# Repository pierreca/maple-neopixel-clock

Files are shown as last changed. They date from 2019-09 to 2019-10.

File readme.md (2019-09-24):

# Maple Neopixel Clock

The goal with this clock project was to learn how to use vcarve and a Shapeoko 3 milling machine.

The electronics are from spare parts I had (I'm sure better components could be found) and the code is quickly put together to make it work but is by no means considered nice or finished.

Finally the PCB was designed to be able to plug a chronodot with an arduino nano and 3 neopixel rings and 2 buttons. I could (probably should?) have chained the rings instead of connecting them separately but didn't think about it when I designed it.

This project is unlikely to evolve or change much :)

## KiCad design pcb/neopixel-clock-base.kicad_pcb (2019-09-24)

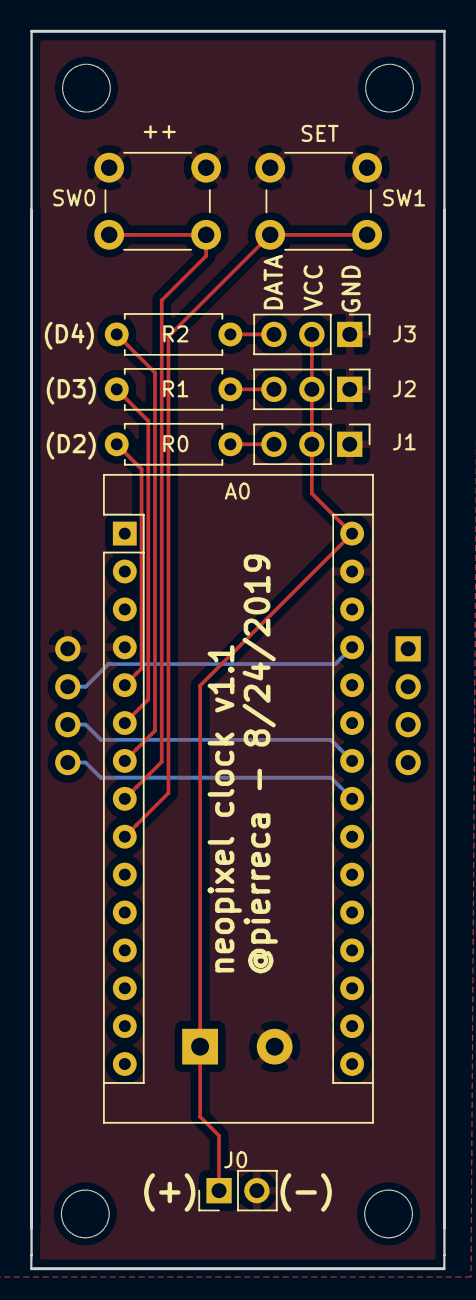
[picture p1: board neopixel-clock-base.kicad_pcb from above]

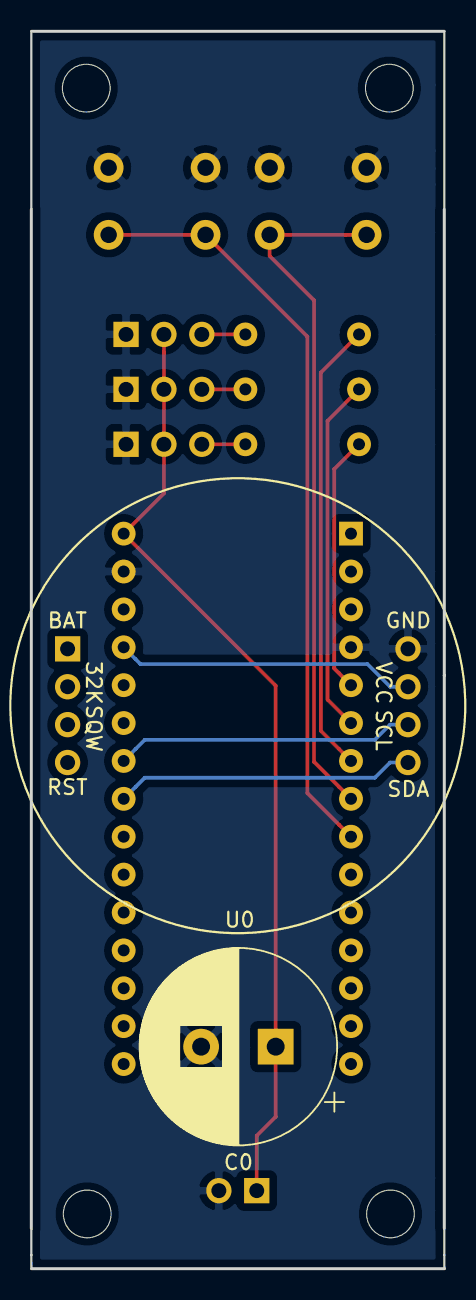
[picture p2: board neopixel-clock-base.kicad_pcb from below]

Board: 2 copper layers, 27.7 x 83.0 mm, 12 parts (2 on the bottom side), 13 nets.

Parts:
A0: Arduino_Nano_v3.x; Arduino_Nano
C0: 100uF 35V; CP_Radial_D13.0mm_P5.00mm
J0: Power; PinHeader_1x02_P2.54mm_Vertical
J1: Neopixel_12; PinHeader_1x03_P2.54mm_Vertical
J2: Neopixel_24; PinHeader_1x03_P2.54mm_Vertical
J3: Neopixel_60; PinHeader_1x03_P2.54mm_Vertical
R0, R1, R2: 300; R_Axial_DIN0207_L6.3mm_D2.5mm_P7.62mm_Horizontal
SW0, SW1: SW_Push; SW_PUSH_6mm
U0: Chronodot; chronodot

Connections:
GND: A0.4, A0.29, C0.2, J0.2, J1.1, J2.1, J3.1, SW0.1, SW1.1, U0.2
unnamed: A0.5, R0.2
unnamed: A0.6, R1.2
unnamed: A0.7, R2.2
unnamed: A0.8, SW0.2
unnamed: A0.9, SW1.2
unnamed: A0.23, U0.8
unnamed: A0.24, U0.6
unnamed: A0.27, U0.4
unnamed: A0.30, C0.1, J0.1, J1.2, J2.2, J3.2
unnamed: J1.3, R0.1
unnamed: J2.3, R1.1
unnamed: J3.3, R2.1

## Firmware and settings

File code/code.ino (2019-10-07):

// Date and time functions using a DS3231 RTC connected via I2C and Wire lib
#include <Wire.h>
#include <Adafruit_NeoPixel.h>
#include "RTClib.h"
#include <avr/interrupt.h>

#define MODE_DISPLAY 0
#define MODE_SET_HOURS 1
#define MODE_SET_MINUTES 2
#define MODE_SET_SECONDS 3

#define HOURS_PIN    2
#define HOURS_PIXELS 12

#define MINUTES_PIN  3
#define MINUTES_PIXELS 24

#define SECONDS_PIN 4
#define SECONDS_PIXELS 60

#define MAX_INTENSITY 255
#define CURRENT_SEC_ANIMATION_RAMP_TIME 600

#define INC_BTN_PIN 5
#define SET_BTN_PIN 6

RTC_DS3231 rtc;
Adafruit_NeoPixel hours_ring = Adafruit_NeoPixel(HOURS_PIXELS, HOURS_PIN, NEO_GRB + NEO_KHZ800);
Adafruit_NeoPixel minutes_ring = Adafruit_NeoPixel(MINUTES_PIXELS, MINUTES_PIN, NEO_GRB + NEO_KHZ800);
Adafruit_NeoPixel seconds_ring = Adafruit_NeoPixel(SECONDS_PIXELS, SECONDS_PIN, NEO_GRB + NEO_KHZ800);

uint8_t sec, prev_sec, current_mode;

DateTime now;

uint32_t get_pixel_color(uint8_t intensity) {
  return hours_ring.Color(intensity / 6, intensity / 2, intensity);
}

void setup () {
  Serial.begin(9600);
  
  delay(3000); // wait for console opening

  if (! rtc.begin()) {
    Serial.println("Couldn't find RTC");
    while (1);
  }

  if (rtc.lostPower()) {
    Serial.println("RTC lost power, lets set the time!");
    // following line sets the RTC to the date & time this sketch was compiled
    rtc.adjust(DateTime(F(__DATE__), F(__TIME__)));
    // This line sets the RTC with an explicit date & time, for example to set
    // January 21, 2014 at 3am you would call:
    // rtc.adjust(DateTime(2014, 1, 21, 3, 0, 0));
  }

  // set button pins as inputs
  pinMode(SET_BTN_PIN, INPUT_PULLUP);
  pinMode(INC_BTN_PIN, INPUT_PULLUP);
 
  hours_ring.begin();
  minutes_ring.begin();
  seconds_ring.begin();
  sec = 0;
  prev_sec = 0;
}

void color_pixels(Adafruit_NeoPixel& ring, uint8_t pixel) {
    ring.clear();
    for (uint8_t i = 0; i <= pixel; i++) {
        ring.setPixelColor(i, get_pixel_color(MAX_INTENSITY));
    }
    ring.show();
}

void display_hours(uint8_t hour_now) {
    uint8_t pix = hour_now % 12;
    color_pixels(hours_ring, pix);
}

void display_minutes(uint8_t minute_now) {
    uint8_t pix = (minute_now * MINUTES_PIXELS / 60) % 60;
    color_pixels(minutes_ring, pix);
}

void display_seconds(uint8_t second_now) {
    uint8_t pix = second_now % 60;
    color_pixels(seconds_ring, pix);
}

void new_minute_animation() {
  for (uint8_t i = 0; i < 60; i++) {
    seconds_ring.setPixelColor(i, 0);
    seconds_ring.show();
    delay(10);
  }
}

void light_up_current_second(uint8_t current_sec) {
  unsigned long current_sec_animation_start = millis(); 
  while (millis() < current_sec_animation_start + CURRENT_SEC_ANIMATION_RAMP_TIME) {
    unsigned long elapsed = millis() - current_sec_animation_start;
    unsigned long intensity = elapsed * MAX_INTENSITY / CURRENT_SEC_ANIMATION_RAMP_TIME;
    seconds_ring.setPixelColor(sec, get_pixel_color(intensity));
    seconds_ring.show();
  }
}

void serial_print_time(uint8_t hours, uint8_t minutes, uint8_t seconds) {
  Serial.print(hours, DEC);
  Serial.print(':');
  Serial.print(minutes, DEC);
  Serial.print(':');
  Serial.print(seconds, DEC);
  Serial.println();
}

void display_time() {
  DateTime now = rtc.now();

  display_hours(now.hour());
  display_minutes(now.minute());
  sec = now.second();

  if (sec != prev_sec) {
    serial_print_time(now.hour(), now.minute(), now.second());
    if (sec == 0) {
      // turn off all seconds pixel in a quick animation around the ring
      new_minute_animation();
    } else {   
      // light up all second pixels until now
      display_seconds(sec - 1);
    }

    // animate current seconds pixel
    light_up_current_second(sec);
    prev_sec = sec;
  }
}

void display_H() {
  hours_ring.clear();
  hours_ring.setPixelColor(3, get_pixel_color(MAX_INTENSITY));
  hours_ring.setPixelColor(9, get_pixel_color(MAX_INTENSITY));
  hours_ring.show();

  minutes_ring.clear();
  for (int i = 3; i <= 9; i++) {
    minutes_ring.setPixelColor(i, get_pixel_color(MAX_INTENSITY));
    minutes_ring.setPixelColor(i + 12, get_pixel_color(MAX_INTENSITY));
  }
  minutes_ring.show();
}

void display_M() {
  hours_ring.clear();
  hours_ring.setPixelColor(1, get_pixel_color(MAX_INTENSITY));
  hours_ring.setPixelColor(11, get_pixel_color(MAX_INTENSITY));
  hours_ring.show();

  minutes_ring.clear();
  for (int i = 3; i <= 9; i++) {
    minutes_ring.setPixelColor(i, get_pixel_color(MAX_INTENSITY));
    minutes_ring.setPixelColor(i + 12, get_pixel_color(MAX_INTENSITY));
  }
  minutes_ring.show();
}

void display_S() {
  hours_ring.clear();
  hours_ring.setPixelColor(3, get_pixel_color(MAX_INTENSITY));
  hours_ring.setPixelColor(9, get_pixel_color(MAX_INTENSITY));
  hours_ring.show();

  minutes_ring.clear();
  for (int i = 0; i <= 3; i++) {
    minutes_ring.setPixelColor(i, get_pixel_color(MAX_INTENSITY));
    minutes_ring.setPixelColor(i + 12, get_pixel_color(MAX_INTENSITY));
  }
  for (int j = 6; j <= 11; j++) {
    minutes_ring.setPixelColor(j, get_pixel_color(MAX_INTENSITY));
    minutes_ring.setPixelColor(j + 12, get_pixel_color(MAX_INTENSITY));
  }
  minutes_ring.show();
}

uint8_t value_set;

bool increase_value_set_if_btn_pressed(uint8_t modulo) {
  bool changed = digitalRead(INC_BTN_PIN) == LOW;
  if (changed) {
    delay(200);
    value_set++;
    if (value_set > modulo - 1) {
      value_set = 0;
    }
  }
  for (int i = 0; i <= value_set; i++) {
    seconds_ring.setPixelColor(i, seconds_ring.Color(0,0,255));
  }

  return changed;
}

void set_time_hours() {
  Serial.println("set hours");
  display_H();
  seconds_ring.clear();
  for (int i = 24; i <= 59; i++) {
    seconds_ring.setPixelColor(i, seconds_ring.Color(255,0,0));
  }
  if(increase_value_set_if_btn_pressed(24)) {
    DateTime now = rtc.now();
    rtc.adjust(DateTime(now.year(), now.month(), now.day(), value_set, now.minute(), now.second()));
  }
  seconds_ring.show();
}

void set_time_minutes() {
  Serial.println("set minutes");
  display_M();
  seconds_ring.clear();
  if(increase_value_set_if_btn_pressed(60)) {
    DateTime now = rtc.now();
    rtc.adjust(DateTime(now.year(), now.month(), now.day(), now.hour(), value_set, now.second()));
  }
  seconds_ring.show();
}

void set_time_seconds() {
  Serial.println("set seconds");
  display_S();
  seconds_ring.clear();
  if(increase_value_set_if_btn_pressed(60)) {
    DateTime now = rtc.now();
    rtc.adjust(DateTime(now.year(), now.month(), now.day(), now.hour(), now.minute(), value_set));
  }
  seconds_ring.show();
}

void loop () {
  if (digitalRead(SET_BTN_PIN) == LOW) {
    current_mode++;
    DateTime now = rtc.now();
    switch (current_mode) {
      case MODE_SET_HOURS:
        value_set = now.hour();
        break;
      case MODE_SET_MINUTES:
        value_set = now.minute();
        break;
      case MODE_SET_SECONDS:
        value_set = now.second();
        break;
      default:
        value_set = 0;
        break;
    }
    delay(300);
  } else {
    switch(current_mode) {
      case MODE_DISPLAY:
        display_time();
        break;
      case MODE_SET_HOURS:
        set_time_hours();
        break;
      case MODE_SET_MINUTES:
        set_time_minutes();
        break;
      case MODE_SET_SECONDS:
        set_time_seconds();
        break;
      default:
        current_mode = MODE_DISPLAY;
        break;
    }
  }
}

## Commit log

2019-09-03 basic code for neopixel clock + adjustments to dps badge + chronodot lib + nixie clock base
    [neopixel-clock-base.kicad_pcb, neopixel-clock-base.sch]
2019-09-08 add v-carve files for cnc milling of the clock face
2019-09-09 add 2 pushbuttons to neopixel clock pcb design
    [neopixel-clock-base.kicad_pcb, neopixel-clock-base.sch]
2019-09-24 Move schematics and PCB design into the pcb folder. Add readme and gitignore files
    [neopixel-clock-base.kicad_pcb, neopixel-clock-base.sch]
2019-10-07 Add prototype code to set the time using buttons
2019-11-30 Add laser-cutter pattern for acrylic rings
